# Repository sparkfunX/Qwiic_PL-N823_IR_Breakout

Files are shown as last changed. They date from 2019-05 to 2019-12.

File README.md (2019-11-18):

SparkFun Qwiic PL-N823 IR Breakout
===================================

SparkFun Qwiic IR Breakout (https://cdn.sparkfun.com/assets/parts/1/4/4/2/8/15804-Qwiic_IR_Breakout-01.jpg)

[*SparkFun Qwiic IR Breakout (SPX-15804)*](https://www.sparkfun.com/products/15804)

PL-N823-01 Lensless IR Sensor breakout with signal amplifier and I2C ADC 

This board allows for digital sensor reading of IR signals from external sources. One such application can be the detection of heat given off by the human body. Operating voltage is 5V for the board as a whole, and while under 1mm thick materials detection can be as far away as 10cm to 20cm.

Repository Contents
-------------------

* **/Documents** - Contains datasheets
* **/Hardware** - Current .brd and .sch files for product

Documentation
-------------

* **[Installing an Arduino Library Guide](https://learn.sparkfun.com/tutorials/installing-an-arduino-library)** - Basic information on how to install an Arduino library.

License Information
-------------------

This product is _**open source**_!

Please review the LICENSE.md file for license information.

If you have any questions or concerns on licensing, please contact technical support on our [SparkFun forums](https://forum.sparkfun.com/viewforum.php?f=152).

Distributed as-is; no warranty is given.

- Your friends at SparkFun.

_<COLLABORATION CREDIT>_

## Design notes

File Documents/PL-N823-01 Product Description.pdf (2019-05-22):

# PL-N823-01 PIR Sensor Breakout

## Product Description

## Description

Friends, Romans, countrymen, lens me your ears…

Ok, that was terrible, my apologies. But while you’re here, you gotta check this out. Kemet Corporation’s lensless passive infrared sensor is really cool! Most infrared sensors need a lens or a line of sight to detect infrared waves. But this small module is sensitive enough to be behind a material and pick up even body heat passing by the surface.

This module has a 60° viewing angle, low power consumption, and multiple material allowances make this module an awesome addition to your infrared needs. Some materials it can hide behind are glass, ABS, or even acrylic. Distances, under these materials, may vary from 10 to 20 cm. However, if you don’t want it hidden then you can add a polyethylene lens for an 1 to 2 m distances.

Now, I’m probably biased to use this as a switch that I can hide and wave my hand across to open a door like a jedi, but there are lots of possibilities for uses. What will you make with it?

## Features

- 60° viewing angle
- Low power consumption
- 10 to 20 cm detecting distances
- 1 to 2 m detecting distances with a polyethylene lens
- Qwiic connectors for ease of use

## Datasheets

PL-N823-01 General (https://datasheet.octopart.com/PL-N823-01-KEMET-datasheet-116838014.pdf)
PL-N823-01 Detailed (https://drive.google.com/open?id=0B0t0MEkE8vqOdExXWmUyZndVek9TdUZCekxFamgxX3UzYWs4) <pdf file needs to be pointed to on our servers, no web location available>

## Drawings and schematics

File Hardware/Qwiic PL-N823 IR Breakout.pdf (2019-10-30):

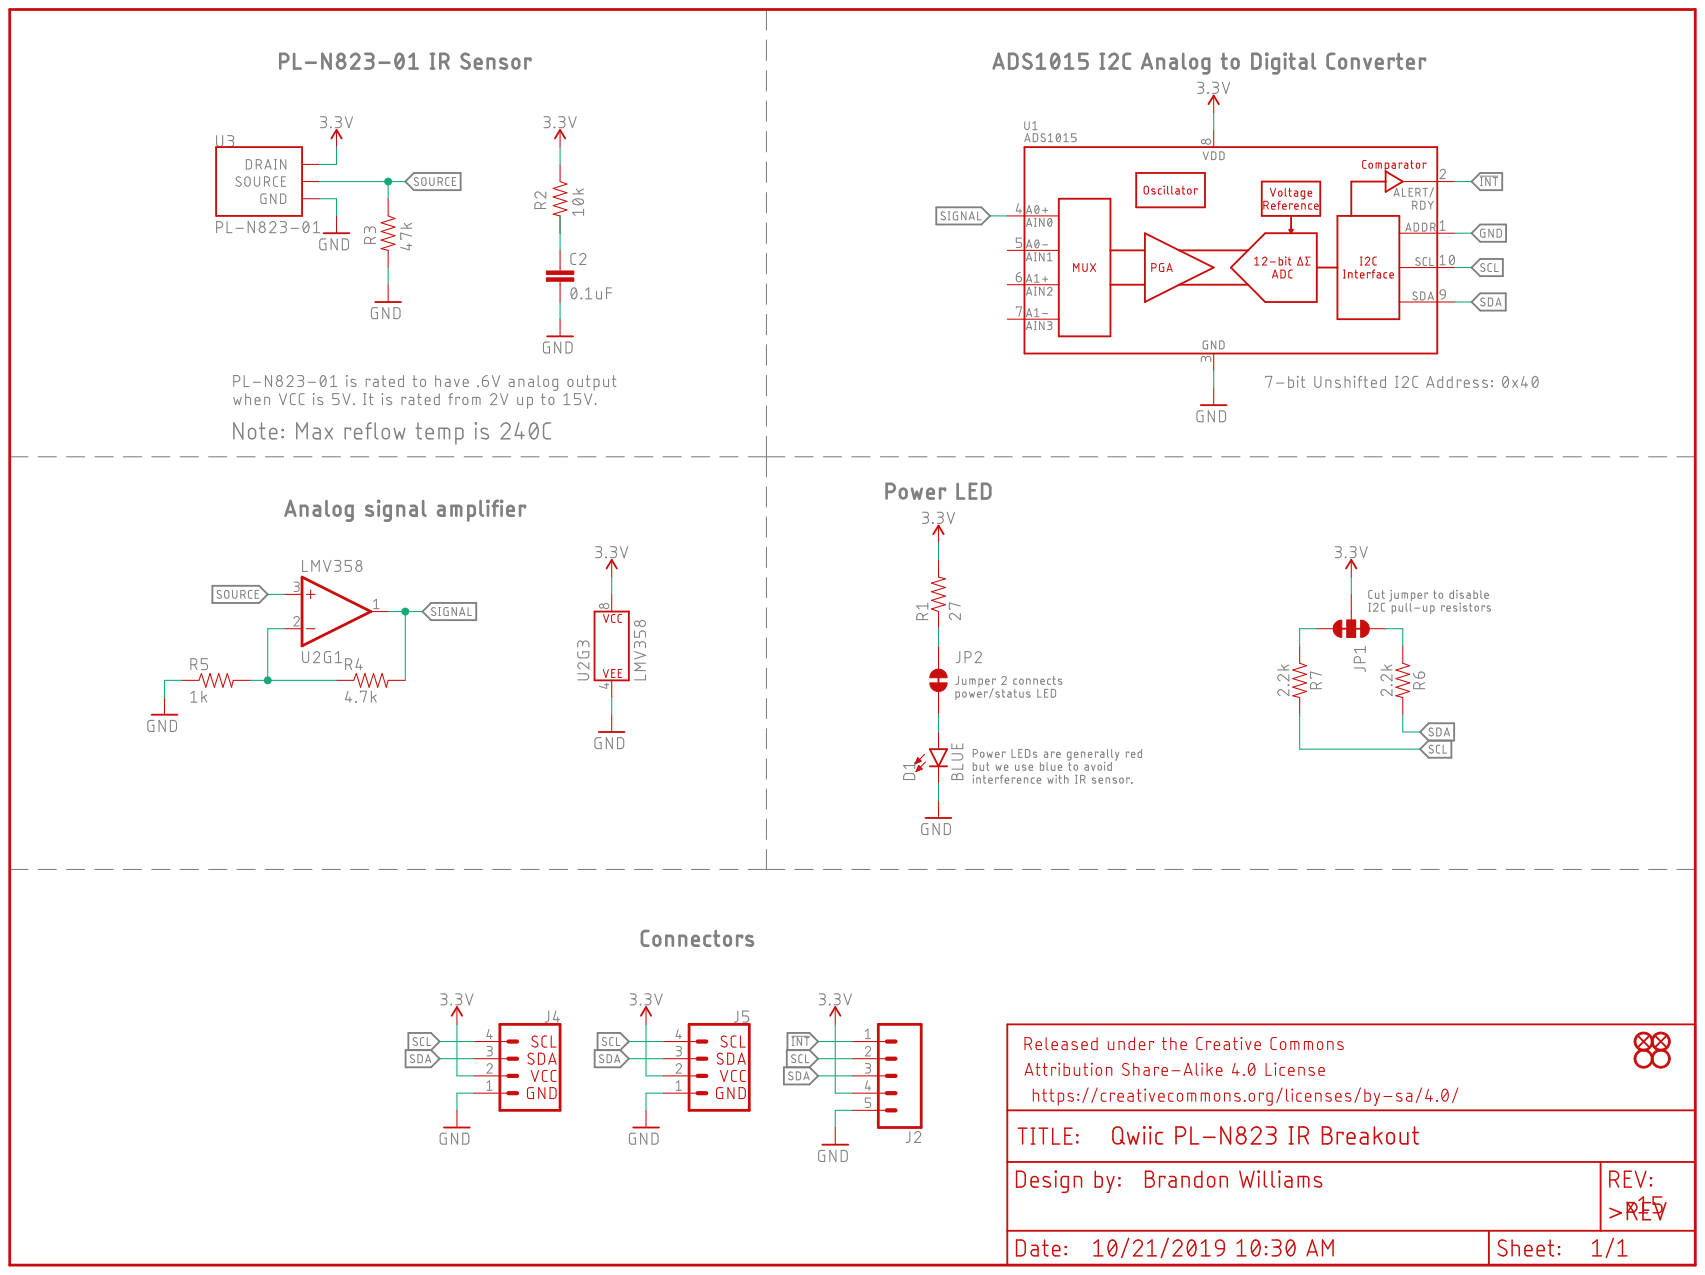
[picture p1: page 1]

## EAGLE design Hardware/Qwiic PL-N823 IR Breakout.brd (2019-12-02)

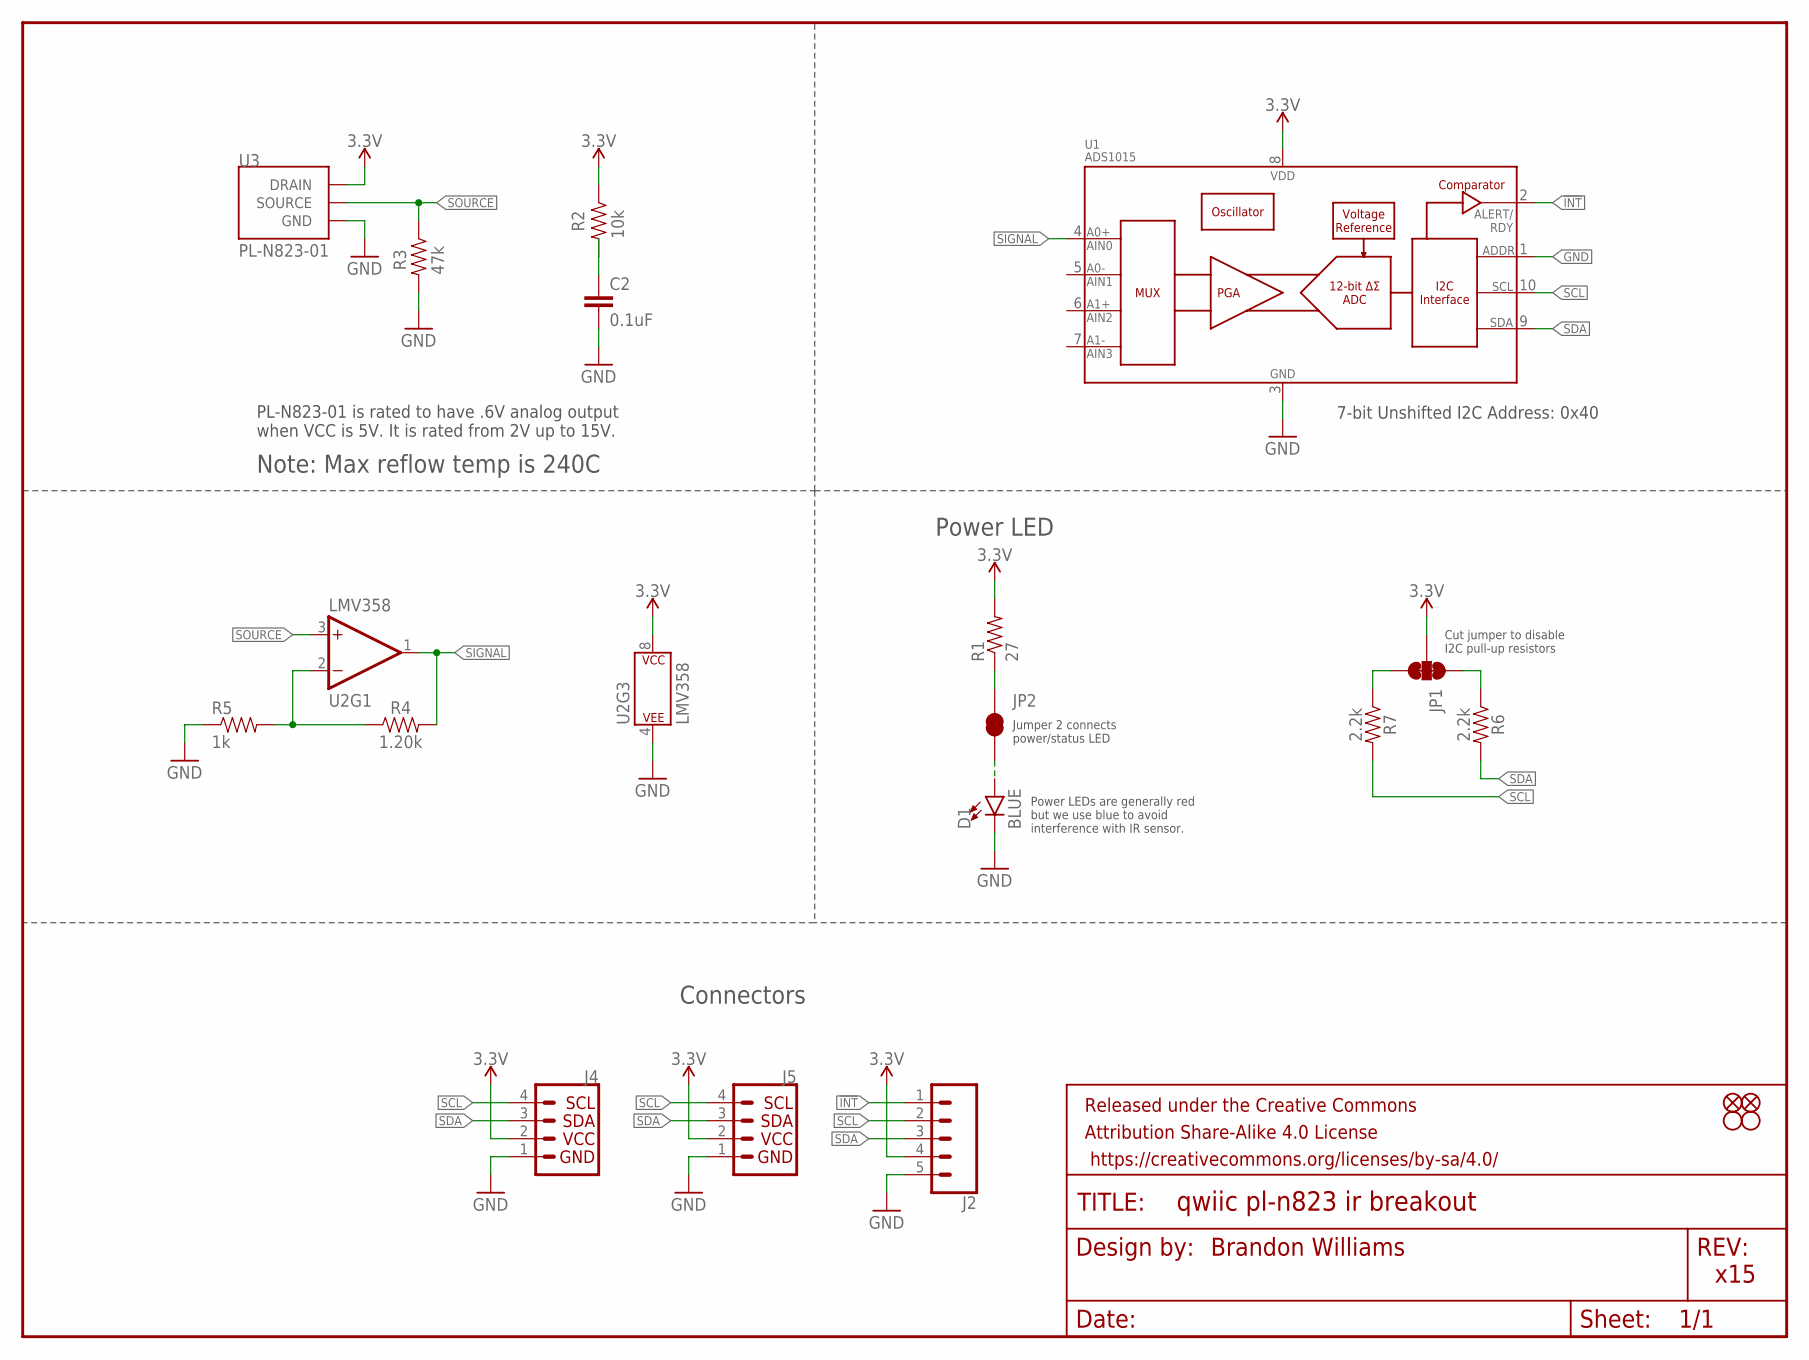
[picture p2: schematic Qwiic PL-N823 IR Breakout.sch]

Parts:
C2: 0.1uF; 0603
D1: BLUE; LED-0603
FD1, FD2: FIDUCIALUFIDUCIAL; FIDUCIAL-MICRO
FRAME1: FRAME-LETTERNO_PACKAGE; DUMMY
H1, H2: STAND-OFFTIGHT; STAND-OFF-TIGHT
J2: CONN_05NO_SILK; 1X05_NO_SILK
J4, J5: QWIIC_CONNECTORJS-1MM; JST04_1MM_RA
JP1: JUMPER-SMT_3_2-NC_TRACE_SILK; SMT-JUMPER_3_2-NC_TRACE_SILK
JP2: JUMPER-SMT_2_NC_TRACE_SILK; SMT-JUMPER_2_NC_TRACE_SILK
R1: 27; 0603
R2: 10k; 0603
R3: 47k; 0603
R4: 1.20k; 0603
R5: 1k; 0603
R6, R7: 2.2k; 0603
U1: ADS1015; MSOP10
U2: LMV358; SO08
U3: PL-N823-01

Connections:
3.3V: J2.4, J4.2, J5.2, JP1.2, R1.2, R2.1, U1.8 (VDD), U2.8 (P$V+), U3.DRAIN
!INT: J2.1, U1.2 (ALERT/RDY)
GND: C2.2, D1.C, J2.5, J4.1, J5.1, R3.2, R5.1, U1.1 (ADDR), U1.3 (VSS), U2.4 (P$V-), U3.GND@1 (GND), U3.GND@2 (GND)
unnamed: R4.1, R5.2, U2.2 (-IN)
unnamed: C2.1, R2.2
unnamed: JP2.1, R1.1
unnamed: JP1.3, R7.1
unnamed: JP1.1, R6.1
unnamed: D1.A, JP2.2
SCL: J2.2, J4.4, J5.4, R7.2, U1.10 (SCL)
SDA: J2.3, J4.3, J5.3, R6.2, U1.9 (SDA)
SIGNAL: R4.2, U1.4 (AIN0), U2.1 (OUT)
SOURCE: R3.1, U2.3 (+IN), U3.SOURCE

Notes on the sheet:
Brandon Williams
x15
7-bit Unshifted I2C Address: 0x40
Power LED
Jumper 2 connects power/status LED
Cut jumper to disable I2C pull-up resistors
PL-N823-01 is rated to have .6V analog output when VCC is 5V. It is rated from 2V up to 15V.
Connectors
Note: Max reflow temp is 240C
Power LEDs are generally red but we use blue to avoid interference with IR sensor.

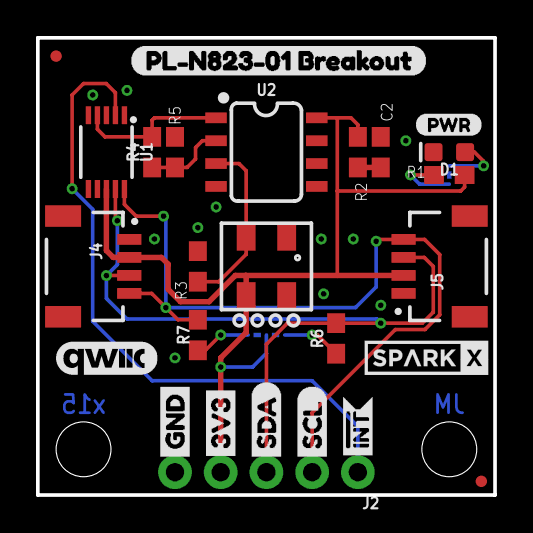
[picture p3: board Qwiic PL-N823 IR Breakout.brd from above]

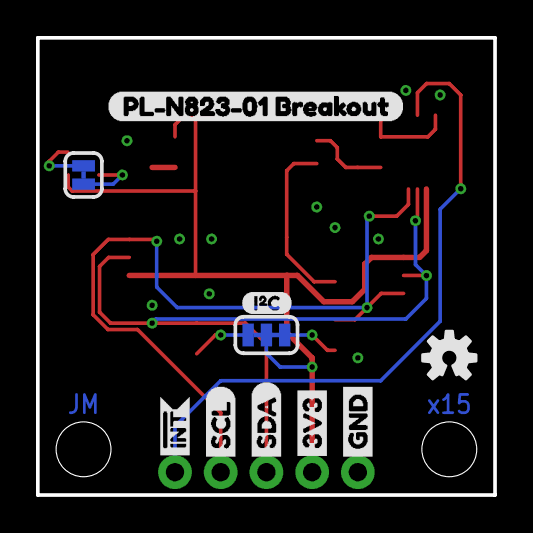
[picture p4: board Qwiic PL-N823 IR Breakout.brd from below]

Board: 2 copper layers, 25.4 x 25.4 mm, 40 parts (10 on the bottom side), 13 nets.

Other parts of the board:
U$1: QWIIC_COPYRIGHT_SMALL
U$2, U$13: SDA-[)
U$3: PRODUCTION_INSTRUCTIONS
U$4, U$8: PL#N823#01_BREAKOUT0
U$5: I_SUPER2_C-()-03
U$6, U$11: INT#-[<-04
U$7: OSHW-LOGO-S
U$9: PWR-()-03
U$10: SPARKX-SMALL
U$12, U$14: SCL-[)
U$15, U$16: 3V3-04
U$17, U$18: GND-04

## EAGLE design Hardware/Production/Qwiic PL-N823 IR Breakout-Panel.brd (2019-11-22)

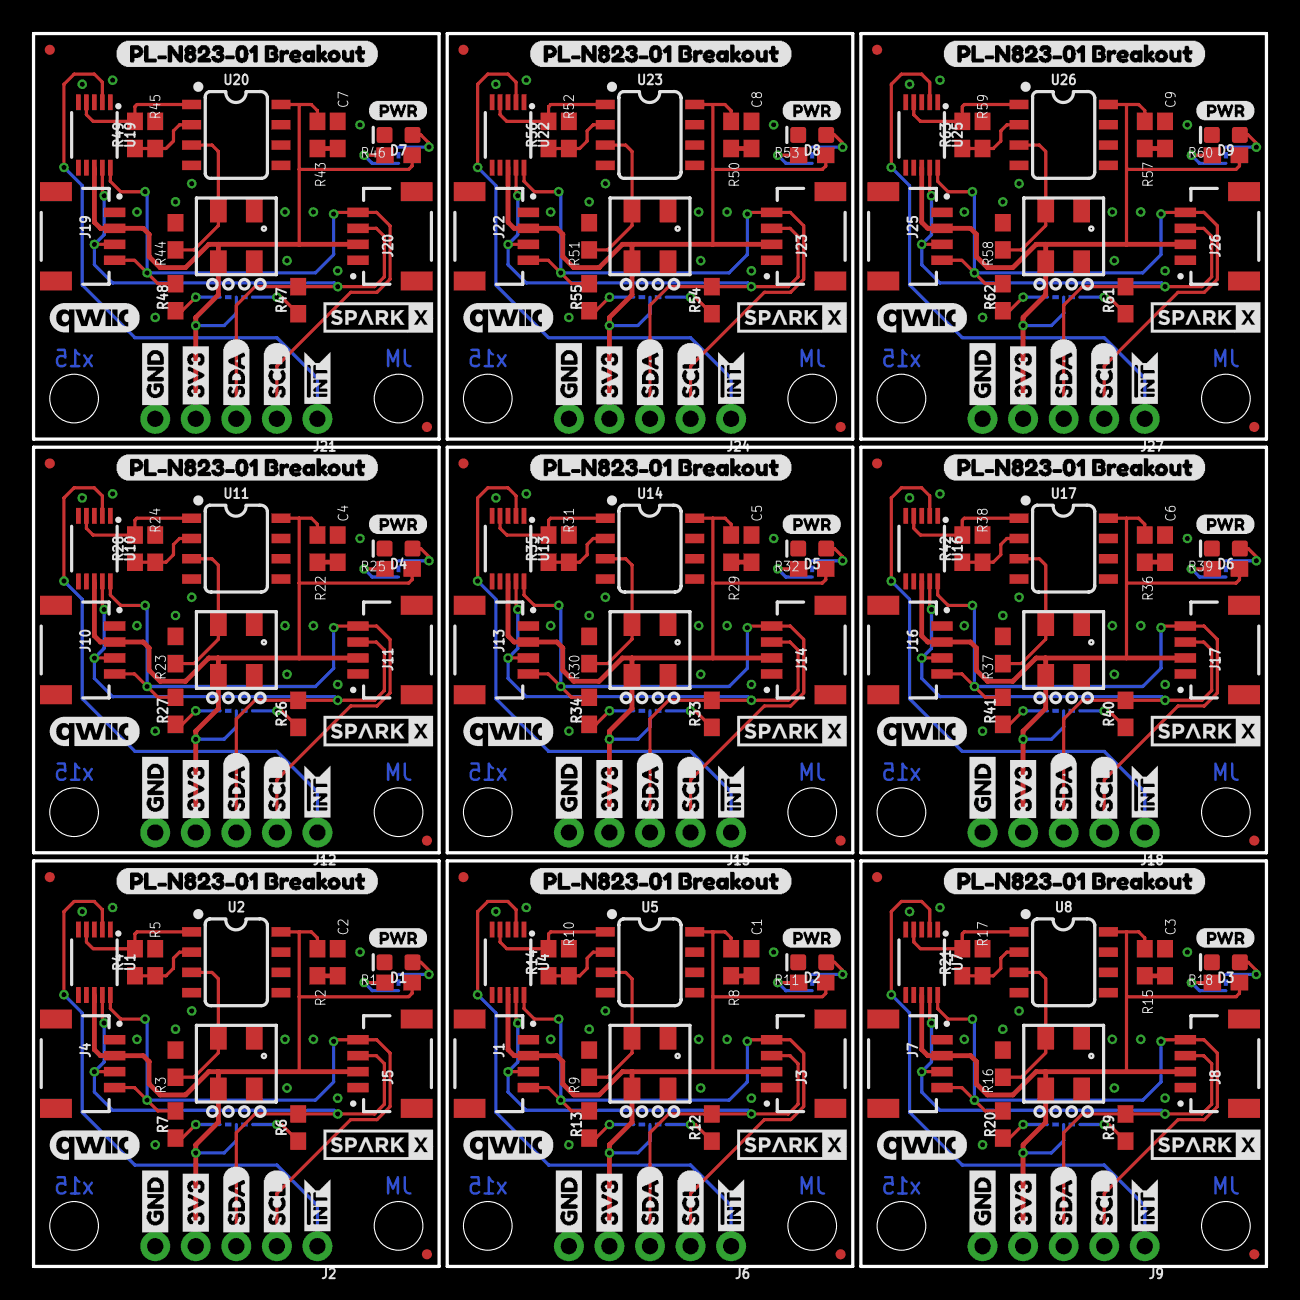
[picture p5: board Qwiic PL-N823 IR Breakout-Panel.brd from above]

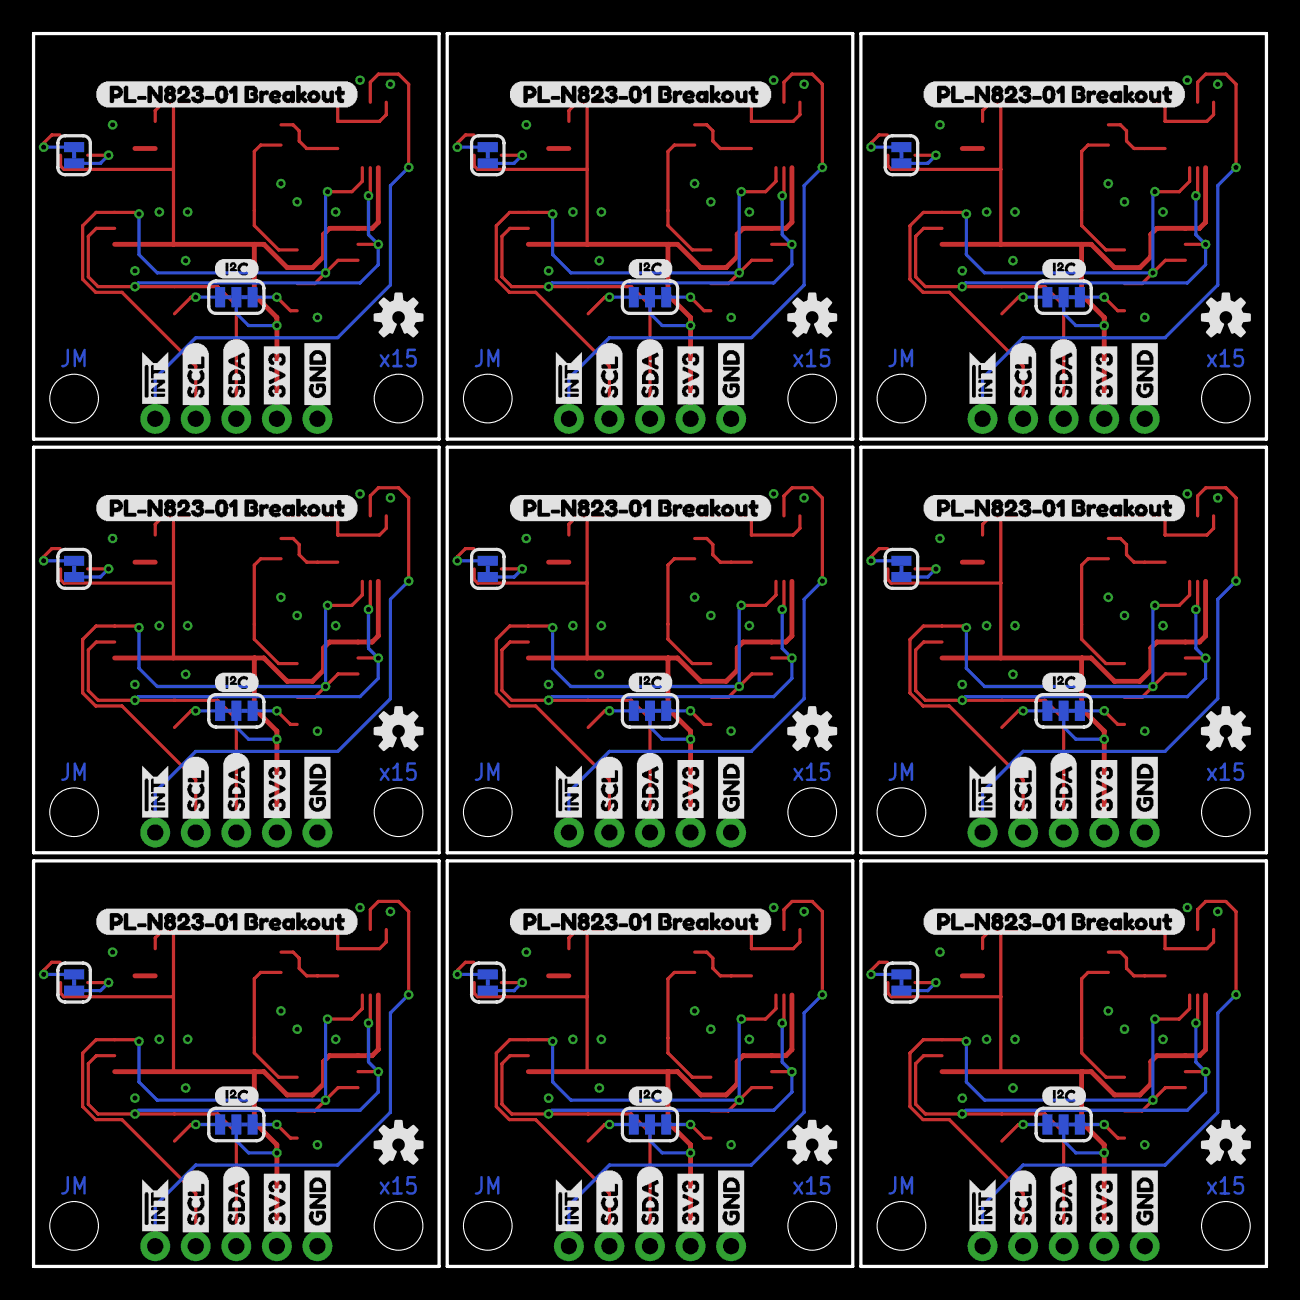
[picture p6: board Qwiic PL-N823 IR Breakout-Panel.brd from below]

Board: 2 copper layers, 77.2 x 77.2 mm, 360 parts (90 on the bottom side), 117 nets.

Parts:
C1, C2, C3, C4, C5, C6, C7, C8, C9: 0.1uF; 0603
D1, D2, D3, D4, D5, D6, D7, D8, D9: BLUE; LED-0603
FD1, FD2, FD3, FD4, FD5, FD6, FD7, FD8, FD9, FD10, FD11, FD12, FD13, FD14, FD15, FD16, FD17, FD18: FIDUCIALUFIDUCIAL; FIDUCIAL-MICRO
FRAME1, FRAME2, FRAME3, FRAME4, FRAME5, FRAME6, FRAME7, FRAME8, FRAME9: FRAME-LETTERNO_PACKAGE; DUMMY
H1, H2, H3, H4, H5, H6, H7, H8, H9, H10, H11, H12, H13, H14, H15, H16, H17, H18: STAND-OFFTIGHT; STAND-OFF-TIGHT
J1, J3, J4, J5, J7, J8, J10, J11, J13, J14, J16, J17, J19, J20, J22, J23, J25, J26: JST04_1MM_RA
J2, J6, J9, J12, J15, J18, J21, J24, J27: 1X05_NO_SILK
JP1, JP3, JP5, JP7, JP9, JP11, JP13, JP15, JP17: JUMPER-SMT_3_2-NC_TRACE_SILK; SMT-JUMPER_3_2-NC_TRACE_SILK
JP2, JP4, JP6, JP8, JP10, JP12, JP14, JP16, JP18: JUMPER-SMT_2_NC_TRACE_SILK; SMT-JUMPER_2_NC_TRACE_SILK
R1, R11, R18, R25, R32, R39, R46, R53, R60: 27; 0603
R2, R8, R15, R22, R29, R36, R43, R50, R57: 10k; 0603
R3, R9, R16, R23, R30, R37, R44, R51, R58: 47k; 0603
R4, R14, R21, R28, R35, R42, R49, R56, R63: 1.20k; 0603
R5, R10, R17, R24, R31, R38, R45, R52, R59: 1k; 0603
R6, R7, R12, R13, R19, R20, R26, R27, R33, R34, R40, R41, R47, R48, R54, R55, R61, R62: 2.2k; 0603
U1, U4, U7, U10, U13, U16, U19, U22, U25: ADS1015; MSOP10
U2, U5, U8, U11, U14, U17, U20, U23, U26: LMV358; SO08
U3, U6, U9, U12, U15, U18, U21, U24, U27: PL-N823-01
U$1, U$22, U$40, U$58, U$76, U$94, U$112, U$130, U$148: QWIIC_COPYRIGHT_SMALL
U$2, U$13, U$24, U$26, U$42, U$44, U$60, U$62, U$78, U$80, U$96, U$98, U$114, U$116, U$132, U$134, U$150, U$152: SDA-[)
U$3, U$36, U$54, U$72, U$90, U$108, U$126, U$144, U$162: PRODUCTION_INSTRUCTIONS
U$4, U$8, U$20, U$32, U$38, U$50, U$56, U$68, U$74, U$86, U$92, U$104, U$110, U$122, U$128, U$140, U$146, U$158: PL#N823#01_BREAKOUT0
U$5, U$33, U$51, U$69, U$87, U$105, U$123, U$141, U$159: I_SUPER2_C-()-03
U$6, U$11, U$34, U$35, U$52, U$53, U$70, U$71, U$88, U$89, U$106, U$107, U$124, U$125, U$142, U$143, U$160, U$161: INT#-[<-04
U$7, U$19, U$37, U$55, U$73, U$91, U$109, U$127, U$145: OSHW-LOGO-S
U$9, U$23, U$41, U$59, U$77, U$95, U$113, U$131, U$149: PWR-()-03
U$10, U$21, U$39, U$57, U$75, U$93, U$111, U$129, U$147: SPARKX-SMALL
U$12, U$14, U$25, U$27, U$43, U$45, U$61, U$63, U$79, U$81, U$97, U$99, U$115, U$117, U$133, U$135, U$151, U$153: SCL-[)
U$15, U$16, U$28, U$29, U$46, U$47, U$64, U$65, U$82, U$83, U$100, U$101, U$118, U$119, U$136, U$137, U$154, U$155: 3V3-04
U$17, U$18, U$30, U$31, U$48, U$49, U$66, U$67, U$84, U$85, U$102, U$103, U$120, U$121, U$138, U$139, U$156, U$157: GND-04

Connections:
3.3V: J2.4, J4.2, J5.2, JP1.2, R1.2, R2.1, U1.8, U2.8, U3.DRAIN
3.3V1: J1.2, J3.2, J6.4, JP3.2, R8.1, R11.2, U4.8, U5.8, U6.DRAIN
3.3V2: J7.2, J8.2, J9.4, JP5.2, R15.1, R18.2, U7.8, U8.8, U9.DRAIN
3.3V3: J10.2, J11.2, J12.4, JP7.2, R22.1, R25.2, U10.8, U11.8, U12.DRAIN
3.3V4: J13.2, J14.2, J15.4, JP9.2, R29.1, R32.2, U13.8, U14.8, U15.DRAIN
3.3V5: J16.2, J17.2, J18.4, JP11.2, R36.1, R39.2, U16.8, U17.8, U18.DRAIN
3.3V6: J19.2, J20.2, J21.4, JP13.2, R43.1, R46.2, U19.8, U20.8, U21.DRAIN
3.3V7: J22.2, J23.2, J24.4, JP15.2, R50.1, R53.2, U22.8, U23.8, U24.DRAIN
3.3V8: J25.2, J26.2, J27.4, JP17.2, R57.1, R60.2, U25.8, U26.8, U27.DRAIN
!INT: J2.1, U1.2
!INT1: J6.1, U4.2
!INT2: J9.1, U7.2
!INT3: J12.1, U10.2
!INT4: J15.1, U13.2
!INT5: J18.1, U16.2
!INT6: J21.1, U19.2
!INT7: J24.1, U22.2
!INT8: J27.1, U25.2
GND: C2.2, D1.C, J2.5, J4.1, J5.1, R3.2, R5.1, U1.1, U1.3, U2.4, U3.GND@1, U3.GND@2
GND1: C1.2, D2.C, J1.1, J3.1, J6.5, R9.2, R10.1, U4.1, U4.3, U5.4, U6.GND@1, U6.GND@2
GND2: C3.2, D3.C, J7.1, J8.1, J9.5, R16.2, R17.1, U7.1, U7.3, U8.4, U9.GND@1, U9.GND@2
GND3: C4.2, D4.C, J10.1, J11.1, J12.5, R23.2, R24.1, U10.1, U10.3, U11.4, U12.GND@1, U12.GND@2
GND4: C5.2, D5.C, J13.1, J14.1, J15.5, R30.2, R31.1, U13.1, U13.3, U14.4, U15.GND@1, U15.GND@2
GND5: C6.2, D6.C, J16.1, J17.1, J18.5, R37.2, R38.1, U16.1, U16.3, U17.4, U18.GND@1, U18.GND@2
GND6: C7.2, D7.C, J19.1, J20.1, J21.5, R44.2, R45.1, U19.1, U19.3, U20.4, U21.GND@1, U21.GND@2
GND7: C8.2, D8.C, J22.1, J23.1, J24.5, R51.2, R52.1, U22.1, U22.3, U23.4, U24.GND@1, U24.GND@2
GND8: C9.2, D9.C, J25.1, J26.1, J27.5, R58.2, R59.1, U25.1, U25.3, U26.4, U27.GND@1, U27.GND@2
unnamed: R4.1, R5.2, U2.2
unnamed: C2.1, R2.2
unnamed: JP2.1, R1.1
unnamed: JP1.3, R7.1
unnamed: JP1.1, R6.1
unnamed: D1.A, JP2.2
unnamed: C1.1, R8.2
unnamed: R10.2, R14.1, U5.2
unnamed: JP3.3, R13.1
unnamed: JP3.1, R12.1
unnamed: D2.A, JP4.2
unnamed: JP4.1, R11.1
unnamed: C3.1, R15.2
unnamed: R17.2, R21.1, U8.2
unnamed: JP5.3, R20.1
unnamed: JP5.1, R19.1
unnamed: D3.A, JP6.2
unnamed: JP6.1, R18.1
unnamed: C4.1, R22.2
unnamed: R24.2, R28.1, U11.2
unnamed: JP7.3, R27.1
unnamed: JP7.1, R26.1
unnamed: D4.A, JP8.2
unnamed: JP8.1, R25.1
unnamed: C5.1, R29.2
unnamed: R31.2, R35.1, U14.2
unnamed: JP9.3, R34.1
unnamed: JP9.1, R33.1
unnamed: D5.A, JP10.2
unnamed: JP10.1, R32.1
unnamed: C6.1, R36.2
unnamed: R38.2, R42.1, U17.2
unnamed: JP11.3, R41.1
unnamed: JP11.1, R40.1
unnamed: D6.A, JP12.2
unnamed: JP12.1, R39.1
unnamed: C7.1, R43.2
unnamed: R45.2, R49.1, U20.2
unnamed: JP13.3, R48.1
unnamed: JP13.1, R47.1
unnamed: D7.A, JP14.2
unnamed: JP14.1, R46.1
unnamed: C8.1, R50.2
unnamed: R52.2, R56.1, U23.2
unnamed: JP15.3, R55.1
unnamed: JP15.1, R54.1
unnamed: D8.A, JP16.2
unnamed: JP16.1, R53.1
unnamed: C9.1, R57.2
unnamed: R59.2, R63.1, U26.2
unnamed: JP17.3, R62.1
unnamed: JP17.1, R61.1
unnamed: D9.A, JP18.2
unnamed: JP18.1, R60.1
SCL: J2.2, J4.4, J5.4, R7.2, U1.10
SCL1: J1.4, J3.4, J6.2, R13.2, U4.10
SCL2: J7.4, J8.4, J9.2, R20.2, U7.10
SCL3: J10.4, J11.4, J12.2, R27.2, U10.10
SCL4: J13.4, J14.4, J15.2, R34.2, U13.10
SCL5: J16.4, J17.4, J18.2, R41.2, U16.10
SCL6: J19.4, J20.4, J21.2, R48.2, U19.10
SCL7: J22.4, J23.4, J24.2, R55.2, U22.10
SCL8: J25.4, J26.4, J27.2, R62.2, U25.10
SDA: J2.3, J4.3, J5.3, R6.2, U1.9
SDA1: J1.3, J3.3, J6.3, R12.2, U4.9
SDA2: J7.3, J8.3, J9.3, R19.2, U7.9
SDA3: J10.3, J11.3, J12.3, R26.2, U10.9
SDA4: J13.3, J14.3, J15.3, R33.2, U13.9
SDA5: J16.3, J17.3, J18.3, R40.2, U16.9
SDA6: J19.3, J20.3, J21.3, R47.2, U19.9
SDA7: J22.3, J23.3, J24.3, R54.2, U22.9
SDA8: J25.3, J26.3, J27.3, R61.2, U25.9
SIGNAL: R4.2, U1.4, U2.1
SIGNAL1: R14.2, U4.4, U5.1
SIGNAL2: R21.2, U7.4, U8.1
SIGNAL3: R28.2, U10.4, U11.1
SIGNAL4: R35.2, U13.4, U14.1
SIGNAL5: R42.2, U16.4, U17.1
SIGNAL6: R49.2, U19.4, U20.1
SIGNAL7: R56.2, U22.4, U23.1
SIGNAL8: R63.2, U25.4, U26.1
SOURCE: R3.1, U2.3, U3.SOURCE
SOURCE1: R9.1, U5.3, U6.SOURCE
SOURCE2: R16.1, U8.3, U9.SOURCE
SOURCE3: R23.1, U11.3, U12.SOURCE
SOURCE4: R30.1, U14.3, U15.SOURCE
SOURCE5: R37.1, U17.3, U18.SOURCE
SOURCE6: R44.1, U20.3, U21.SOURCE
SOURCE7: R51.1, U23.3, U24.SOURCE
SOURCE8: R58.1, U26.3, U27.SOURCE

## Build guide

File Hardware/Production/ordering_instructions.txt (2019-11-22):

panel size, 78x78mm
PCB thickness, 1.6mm
number of layers, 2
soldermask color, Black
silkscreen color, White
oz copper, 1oz
finish, HASL lead free
stencils, top
pcs per panel, 9
min trace width, 0.203200mm / 0.008000in
min drill size, 0.304800mm / 0.012000in

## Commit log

2019-06-11 Add panel
    [Qwiic PL-N823 IR Breakout-Panel.GBL, Qwiic PL-N823 IR Breakout-Panel.GBO, Qwiic PL-N823 IR Breakout-Panel.GBS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]
2019-06-11 Add no clean note. Change to blue power LED.
    [Qwiic PL-N823 IR Breakout.brd, Qwiic PL-N823 IR Breakout.sch]
2019-11-18 Updated amplifier circuit
    [Qwiic PL-N823 IR Breakout.brd, Qwiic PL-N823 IR Breakout.sch]
2019-11-22 New panel and output files with correct amp circuit
    Changed amplification gain factor
    [Qwiic PL-N823 IR Breakout-Panel.GBL, Qwiic PL-N823 IR Breakout-Panel.GBO, Qwiic PL-N823 IR Breakout-Panel.GBS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]
2019-12-02 Transition to production: Added PROD_ID of IR sensor
    [Qwiic PL-N823 IR Breakout.brd, Qwiic PL-N823 IR Breakout.sch]

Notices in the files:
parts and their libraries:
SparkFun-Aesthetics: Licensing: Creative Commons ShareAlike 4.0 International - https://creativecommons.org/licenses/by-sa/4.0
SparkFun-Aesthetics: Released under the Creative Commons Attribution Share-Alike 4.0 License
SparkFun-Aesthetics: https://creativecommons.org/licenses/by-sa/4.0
